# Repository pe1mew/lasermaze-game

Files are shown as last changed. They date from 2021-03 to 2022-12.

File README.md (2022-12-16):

# lasermaze-game
A laser maze game designed for BULA2022 

# Work in progress
This is work in progress. Thing may be added or changed without notice.

# Directions
The Architecture of the laser maze can be found [here](Architecture/architecture.md).

# Questions?
If you have any question? please raise an issue and I will ook in to it.

### Disclaimer
The lasermaze-game is distributed in the hope that it will be useful, but WITHOUT ANY WARRANTY; without even the 
implied warranty of MERCHANTABILITY or FITNESS FOR A PARTICULAR PURPOSE.
  
### License
The lasermaze-game is free software and hardware: 
you can redistribute it and/or modify it under the terms of a Creative Commons Attribution-NonCommercial 4.0 International License (http://creativecommons.org/licenses/by-nc/4.0/) by PE1MEW (http://pe1mew.nl) E-mail: pe1mew@pe1mew.nl

<br />This work is licensed under a <a rel="license" href="http://creativecommons.org/licenses/by-nc/4.0/">Creative Commons Attribution-NonCommercial 4.0 International License</a>.

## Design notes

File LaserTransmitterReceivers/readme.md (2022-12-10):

# What to use, where to buy

The following links provide an example. Find the cheapest yourself!

## Transmitter
The laser transmitters are [KY-008 650nm Laser sensor Module 6mm 5V 5mW Red Laser Dot Diode Copper Head KY008](https://www.aliexpress.com/item/4000693969769.html?spm=a2g0o.cart.0.0.43a738dam0hMLE&mp=1) as can found Aliexpress or a equivalent.

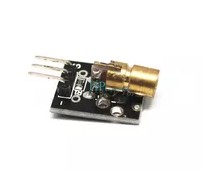
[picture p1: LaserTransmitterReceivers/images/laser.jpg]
laser


## Receptor
For the receivers a LDR prototype board is used: [Photoresistor (LDR) Sensor Module Detects Light Sensitive Photodiode for Arduino](https://www.aliexpress.com/item/32452315745.html) as can found Aliexpress or a equivalent.

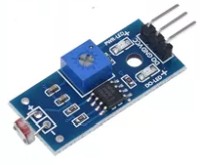
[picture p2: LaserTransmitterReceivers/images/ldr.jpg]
ldr


## Magnets
The magnets to stick the receptors and transmittors to a metal object are [Circular Magnets sheet 15mm X 6mm Round Neodymium Magnet Strong N35 15x6mm Permanent Disc Magnet 15*6 mm](https://www.aliexpress.com/item/1005001581640011.html) as can be found on Aliexpress.

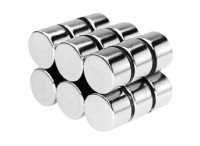
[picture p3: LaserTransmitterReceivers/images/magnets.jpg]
magnets


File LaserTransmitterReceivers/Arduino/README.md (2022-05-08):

# Software for ESP8266 GPIO TX and RX controller
This is the software for the ESP8266 controller boards

## Depenencies
The following dependencies shall be adressed:

### Arduino IDE
Although the software can be used in platformio without any problem, this repository is providing setup for Arduino IDE. 

 - Download the latetst version of Arduino from https://support.arduino.cc/hc/en-us/categories/360002212660-Software-and-Downloads

### Install ESP8266 Board support
 - In settings, add the following url for board support: ```http://arduino.esp8266.com/stable/package_esp8266com_index.json```
 - In "Tools > Board: -> Boards Manager..."  add ESP8266 comunity boards.
 
### Install libraries
 - In "Sketch > Include Library -> Manage Libraries..."  add "PubSubClient" by Nick O'Leary.

## Transmitter

## Receptor

### Disclaimer
The lasermaze-game is distributed in the hope that it will be useful, but WITHOUT ANY WARRANTY; without even the 
implied warranty of MERCHANTABILITY or FITNESS FOR A PARTICULAR PURPOSE.
  
### License
The lasermaze-game is free software and hardware: 
you can redistribute it and/or modify it under the terms of a Creative Commons Attribution-NonCommercial 4.0 International License (http://creativecommons.org/licenses/by-nc/4.0/) by PE1MEW (http://pe1mew.nl) E-mail: pe1mew@pe1mew.nl

<br />This work is licensed under a <a rel="license" href="http://creativecommons.org/licenses/by-nc/4.0/">Creative Commons Attribution-NonCommercial 4.0 International License</a>.

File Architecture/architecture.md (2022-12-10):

# Architecture

The lasermaze is build upon a Raspberry-Pi with Node-red and is visualised in the following component diagram: 

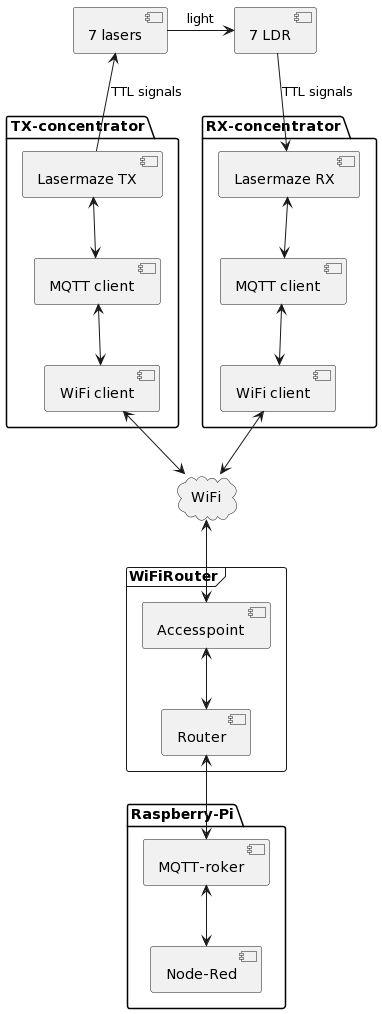
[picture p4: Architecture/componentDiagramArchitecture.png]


The lasers and receivers are connected to a concentrator who control the transmitters and read the receivers. The concentrators connect to the WiFi network so that the MQTT client in the concentrator can connect to the MQTT broker for command and control. 

The Node-red instance is running flows that will implement the game logic. Nod-red is connected to the MQTT broker for command and control of the concentrators.

Lasers are swithed on and off with a messgage in the associated MQTT topic. Receivers report their status on change (detect light or not) with a messgage in the associated MQTT topic. 

At a regular interval the concentrators are polled by the game logic in Node-red. This will allow detection of missed messages as well as a an indication that a concentrator is connected. A connected concentrator that is polled regularly will have a red- blinking led.

## Software
The software required for the Lasermaze is: 

 - Node-red (hart of the system)
 - mosquitto MQTT broker (to interconnect all components of the lasermaze)
 - Arduino (to program the ESP8266)
 - Programcode for the TX- and RX-concentrators. (Avialable in this repository)

## Hardware
The following hardware is required:

 - A computer that can run the software specified above (I used a Raspberry-Pi 4 with a touch screen)
 - Any Wifi-accesspoint with a router that has a DHCP-server. 
 - ESP8266 D1 mini for each TX- and RX-concentrator (fits on the concentrator boards in this repository) 
 - Laser emitters (see [components specified here..](../LaserTransmitterReceivers/readme.md))
 - LDR light detectors (see [components specified here..](../LaserTransmitterReceivers/readme.md))
 - Magnets are optional (see [components specified here..](../LaserTransmitterReceivers/readme.md)
 - PLA to print the laser transmitter and receiver mounts.

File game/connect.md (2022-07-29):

# Connection details of laser emitters and detectors

## emitter

```
            Wire connector
   +---------+-----+
   |         |  0  | negative (-) ground
+-------+    +-----+
| laser |    |  0  | 
+-------+    +-----+
   |         |  0  | positive (+) VCC
   +---------+-----+

```

## detector

```
            Wire connector
   +---+---+-+-----+
   |   | P | |  0  | positive (+) VCC
  /-\  +---+ +-----+
 |LDR|       |  0  | negative (-) ground
  \-/        +-----+
   |         |  0  | output 
   +---------+-----+

```

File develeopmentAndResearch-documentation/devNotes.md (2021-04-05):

# Development notes
These notes contain all information about the architecture and implementation details of the lasermaze. 

# information

## painlessMesh
This a mesh at layer 3 of the OSI-model that implements a network layer. It is connectionless and without confirmation. (See: https://gitlab.com/painlessMesh/painlessMesh/-/wikis/home) Messages are not acknowledged. This should be implemented at application level. 

# LaserMaze requirements

- Detection of events shall not be missed.
- Events shall be transported "fast" to the cental processing unit. (what "fast enough" is shall be determinated)

# Lasermaze architecture.

laser maze is build of the following units:

1. Laser transmitter-detector pairs.
2. transmitter and detector controllers.
3. Auxillary devices like sirens, stobe lights, buttons, PIR-detectors.
3. Auxillary controllers for input and output devices. 
4. controller to MQTT bridge.
5. central game contoller. 

## Laser transmitter-detector pairs. 
These pairs consist of a laser transmitter and a laser detector. Both are installed oposite of each other and controlled by a concentrator that serves a group of lasers and detectors.

## transmitter and detector controllers.
A controller serves only inputs or outputs transmitters or detectors. The maximum number of transmitters or detectors is 8 per concentrator

## Auxillary devices
Auxillary devices are devices that add elements to the game other than the laser transmitters or detectors. 
These can be: 

- outputs: 
	- sirens, 
	- stobe lights, 
- Inputs: 
	- buttons, 
	- PIR-detectors,
- etc.

## Auxillary controllers

## controller to MQTT bridge

## central game contoller.

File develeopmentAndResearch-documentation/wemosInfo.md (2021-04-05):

# wemose ESP8266 D1 Mini

# pin-layout

D1 Mini|GPIO|Type|Function                       |Lasermaze
-------|----|----|-------------------------------|--------------
TX     |1   |I/O |TXD Transmit Data              |Not available
RX     |3   |I/O |RXD Receive Data               |Not available
A0     |A0  |I   |Analog-Input (max. 3,3V)       |tbd.
D0     |16  |I/O |                               |Available
D1     |5   |I/O |SCL I2C Interface              |Available
D2     |4   |I/O |SDA I2C Interface              |Available
D3     |0   |I/O |10k Pull-Up                    |Available
D4     |2   |I/O |10k Pull-Up Built-in LED       |tbd.
D5     |14  |I/O |SCK SPI Interface              |Available
D6     |12  |I/O |MISO SPI Interface             |Available
D7     |13  |I/O |MOSI SPI Interface             |Available
D8     |15  |I/O |SS 10k Pull-Down SPI Interface |Available
G      |GND |-   |Ground                         |
5V     |5V  |I   |RAW VCC (5V)                   |
3V3    |3V3 |O   |3,3V output                    |
RST    |RST |I   |Reset                          |

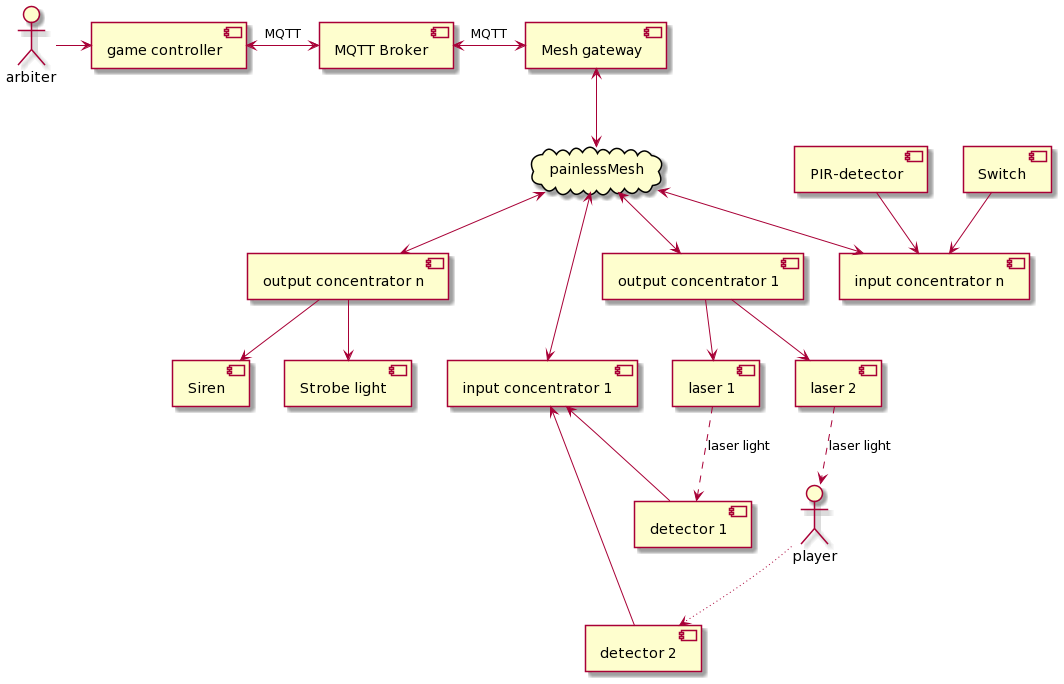
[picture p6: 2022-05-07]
develeopmentAndResearch-documentation/images/PlantUMLComponentDiagram.png

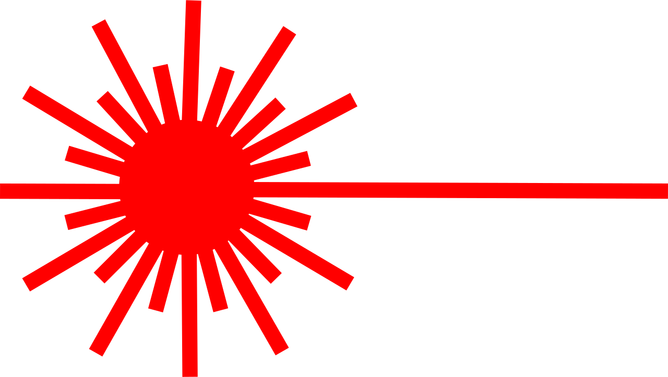
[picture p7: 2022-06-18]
develeopmentAndResearch-documentation/inspiration/1280px-Sailing_laser.svg.png

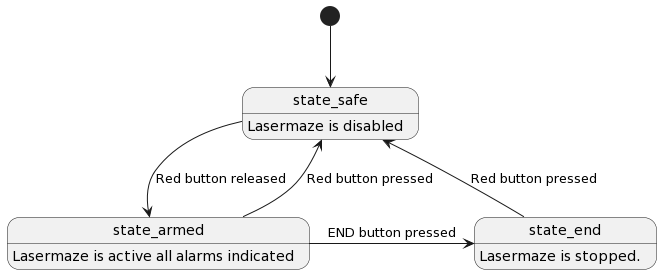
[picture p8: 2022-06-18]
NodeRed/stateDiagram.png

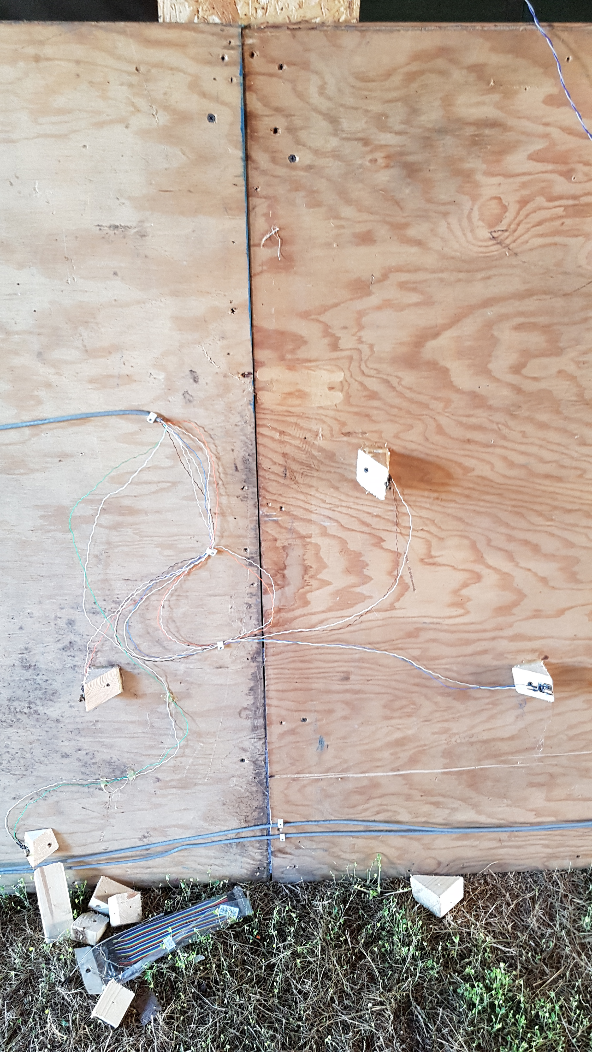
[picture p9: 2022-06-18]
develeopmentAndResearch-documentation/inspiration/2018-08-10 10.22.27.jpg

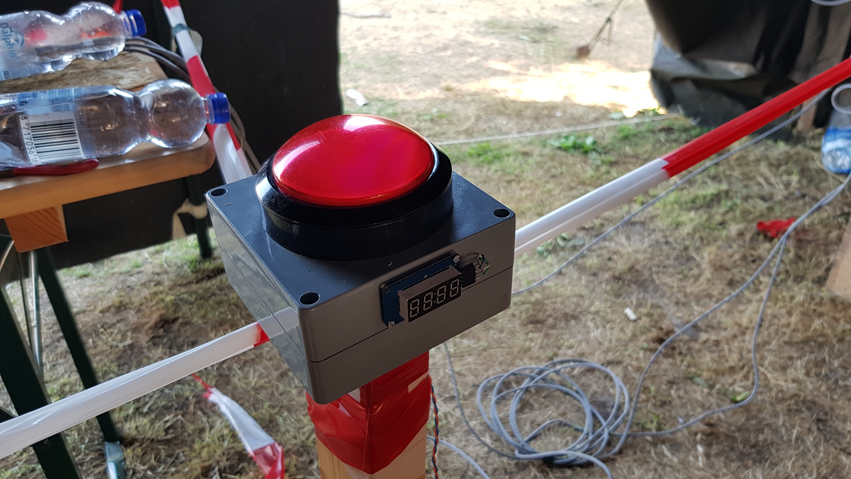
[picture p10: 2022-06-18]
develeopmentAndResearch-documentation/inspiration/2018-08-10 10.23.28.jpg

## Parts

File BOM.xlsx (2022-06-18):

 | Reference | Quantity | totaal | Value | Footprint | aanwezig
Relay | C1 | 1 | 2 | 0,22uF | Capacitor_THT:CP_Radial_D5.0mm_P2.00mm
Relay | C3 C4 C5 C6 C15 C16 C17 C18 | 8 | 8 | 1n | Capacitor_SMD:C_0805_2012Metric_Pad1.18x1.45mm_HandSolder
Relay | C2 | 1 | 2 | 0,1uF | Capacitor_THT:CP_Radial_D5.0mm_P2.00mm
Relay | D1 | 1 | 1 | 1N4007 | Diode_THT:D_DO-41_SOD81_P12.70mm_Horizontal
Relay | D3 D4 D5 D6 D10 D11 D12 D13 | 8 | 8 | LED | LED_SMD:LED_0805_2012Metric_Pad1.15x1.40mm_HandSolder
Relay | D7 D8 D9 D14 D15 D16 D17 D18 | 8 | 16 | 1N4148 | Diode_THT:D_DO-35_SOD27_P7.62mm_Horizontal
Relay | D2 | 1 | 2 | GREEN | LED_SMD:LED_0805_2012Metric_Pad1.15x1.40mm_HandSolder
Relay | J1 - J9 | 9 | 9 | V-IN | TerminalBlock:TerminalBlock_Altech_AK300-2_P5.00mm
Relay | Q1 Q2 Q3 Q4 Q5 Q6 Q7 Q8 | 8 | 8 | 85N3LHS | Package_TO_SOT_THT:SIPAK_Vertical
Relay | R2 R3 R4 R5 R10 R11 R12 R13 | 8 | 8 | 1k | Resistor_SMD:R_0805_2012Metric_Pad1.20x1.40mm_HandSolder
Relay | R1 R6 R7 R8 R9 R14 R15 R16 R17 | 9 | 9 | 150ohm | Resistor_SMD:R_0805_2012Metric_Pad1.20x1.40mm_HandSolder
Relay | R18 R19 R20 R21 R22 R23 R24 R25 | 8 | 8 | SRD-05VDC-SL-C | components:SRD-05VDC-SL-C | TRUE
Relay | U1 | 1 | 2 | WeMos_D1_mini | Module:WEMOS_D1_mini_light | TRUE
Relay | U2 | 1 | 2 | L7805 | Package_TO_SOT_THT:TO-220-3_Horizontal_TabDown
InOut | C1 | 1 | 6 | 0,22uF | Capacitor_THT:CP_Radial_D5.0mm_P2.00mm
InOut | C2 | 1 | 6 | 0,1uF | Capacitor_THT:CP_Radial_D5.0mm_P2.00mm
InOut | C3 C4 C5 C6 C7 C8 C9 C10 C11 C12 C13 C14 C15 C16 C17 C18 C19 C20 C21 C22 C23 C24 C25 C26 | 24 | 72 | 1n | Capacitor_SMD:C_0805_2012Metric_Pad1.18x1.45mm_HandSolder
InOut | D1 | 1 | 6 | 1N4007 | Diode_THT:D_DO-41_SOD81_P12.70mm_Horizontal
Output | D3 D4 D5 D6 D10 D11 D12 D13 | 8 | 24 | LED | LED_SMD:LED_0805_2012Metric_Pad1.15x1.40mm_HandSolder
Output | D7 D8 D9 D14 D15 D16 D17 | 7 | 21 | BAT54S | Package_TO_SOT_SMD:SOT-23
InOut | D2 | 1 | 6 | GREEN | LED_SMD:LED_0805_2012Metric_Pad1.15x1.40mm_HandSolder
Always | J1-J9 | 9 | 54 | V-IN | TerminalBlock:TerminalBlock_Altech_AK300-2_P5.00mm
InOut | JP1 JP2 JP3 JP4 JP5 JP6 JP7 | 7 | 42 | inputEnable | Jumpers:SMT-JUMPER_2_NO_SILK
Output | Q1 Q2 Q3 Q4 Q5 Q6 Q7 Q8 | 8 | 24 | 85N3LHS | Package_TO_SOT_THT:SIPAK_Vertical
Output | R2 R3 R4 R5 R10 R11 R12 R13 | 8 | 24 | 1k | Resistor_SMD:R_0805_2012Metric_Pad1.20x1.40mm_HandSolder
Output | R1 R6 R7 R8 R9 R14 R15 R16 R17 | 9 | 27 | 150ohm | Resistor_SMD:R_0805_2012Metric_Pad1.20x1.40mm_HandSolder
InOut | U1 | 1 | 6 | WeMos_D1_mini | Module:WEMOS_D1_mini_light | TRUE
InOut | U2 | 1 | 6 | L7805 | Package_TO_SOT_THT:TO-220-3_Horizontal_TabDown
 | PCB sets of 2 |  | 3
 |  | 8 |  | 0,1uF | Capacitor_THT:CP_Radial_D5.0mm_P2.00mm
 |  | 8 |  | 0,22uF | Capacitor_THT:CP_Radial_D5.0mm_P2.00mm
 |  | 36 |  | 150ohm | Resistor_SMD:R_0805_2012Metric_Pad1.20x1.40mm_HandSolder
 |  | 32 |  | 1k | Resistor_SMD:R_0805_2012Metric_Pad1.20x1.40mm_HandSolder
 |  | 80 |  | 1n | Capacitor_SMD:C_0805_2012Metric_Pad1.18x1.45mm_HandSolder
 |  | 7 |  | 1N4007 | Diode_THT:D_DO-41_SOD81_P12.70mm_Horizontal
 |  | 16 |  | 1N4148 | Diode_THT:D_DO-35_SOD27_P7.62mm_Horizontal
 |  | 32 |  | 85N3LHS | Package_TO_SOT_THT:SIPAK_Vertical
 |  | 21 |  | BAT54S | Package_TO_SOT_SMD:SOT-23
 |  | 8 |  | GREEN | LED_SMD:LED_0805_2012Metric_Pad1.15x1.40mm_HandSolder
 |  | 8 |  | L7805 | Package_TO_SOT_THT:TO-220-3_Horizontal_TabDown
 |  | 32 |  | LED | LED_SMD:LED_0805_2012Metric_Pad1.15x1.40mm_HandSolder
 |  | 8 |  | SRD-05VDC-SL-C | components:SRD-05VDC-SL-C
 |  | 63 |  | V-IN | TerminalBlock:TerminalBlock_Altech_AK300-2_P5.00mm
 |  | 8 |  | WeMos_D1_mini | Module:WEMOS_D1_mini_light

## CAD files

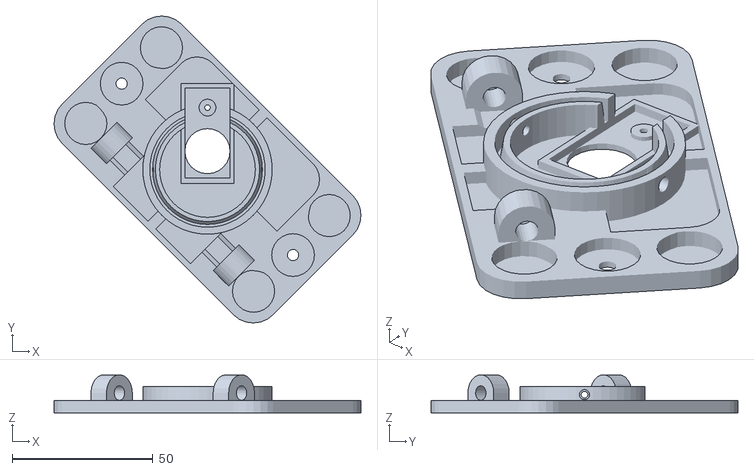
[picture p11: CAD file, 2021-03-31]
LaserTransmitterReceivers/3d/laserReceptor/LaserMazeReceptor_020_fixed.stl
109.1 x 109.1 x 13.5

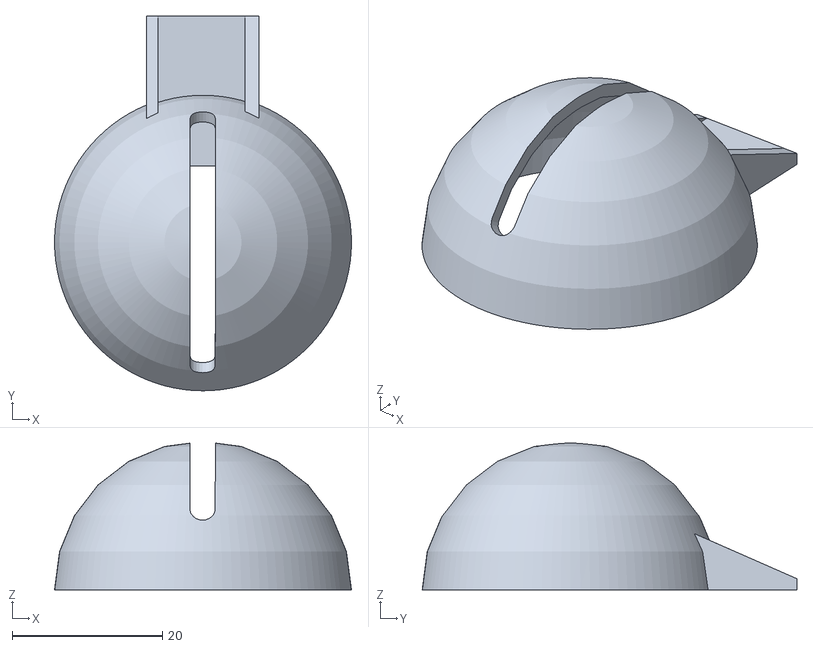
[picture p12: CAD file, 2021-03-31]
LaserTransmitterReceivers/3d/laserTransmitter/LaserMazeTransmitterInsert_007_fixed.stl
39.6 x 50.0 x 19.6

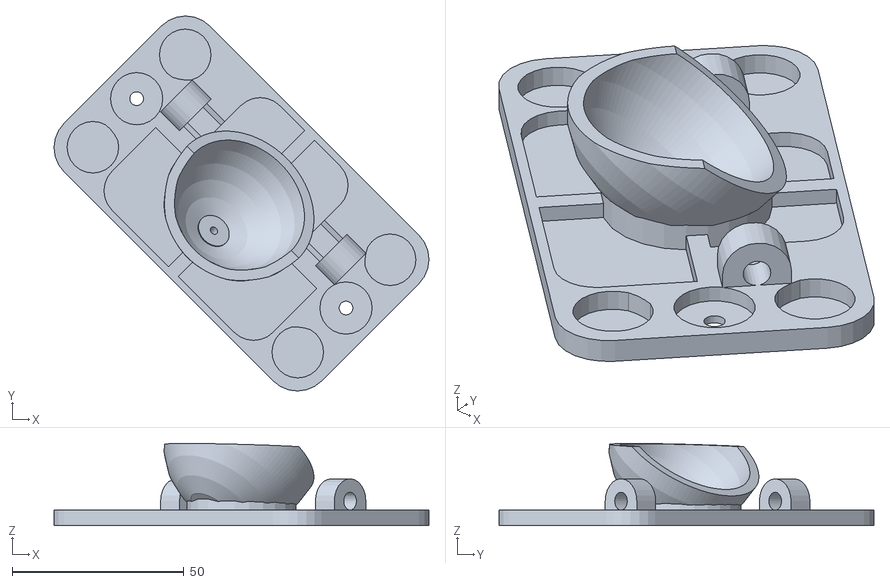
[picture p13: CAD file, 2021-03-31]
LaserTransmitterReceivers/3d/laserTransmitter/LaserMazeTransmitter_012_fixed.stl
109.1 x 109.1 x 23.9

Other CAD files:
LaserTransmitterReceivers/3d/laserReceptor/LaserMazeReceptor_020.skp
LaserTransmitterReceivers/3d/laserTransmitter/LaserMazeTransmitterInsert_007.skp
LaserTransmitterReceivers/3d/laserTransmitter/LaserMazeTransmitter_012.skp

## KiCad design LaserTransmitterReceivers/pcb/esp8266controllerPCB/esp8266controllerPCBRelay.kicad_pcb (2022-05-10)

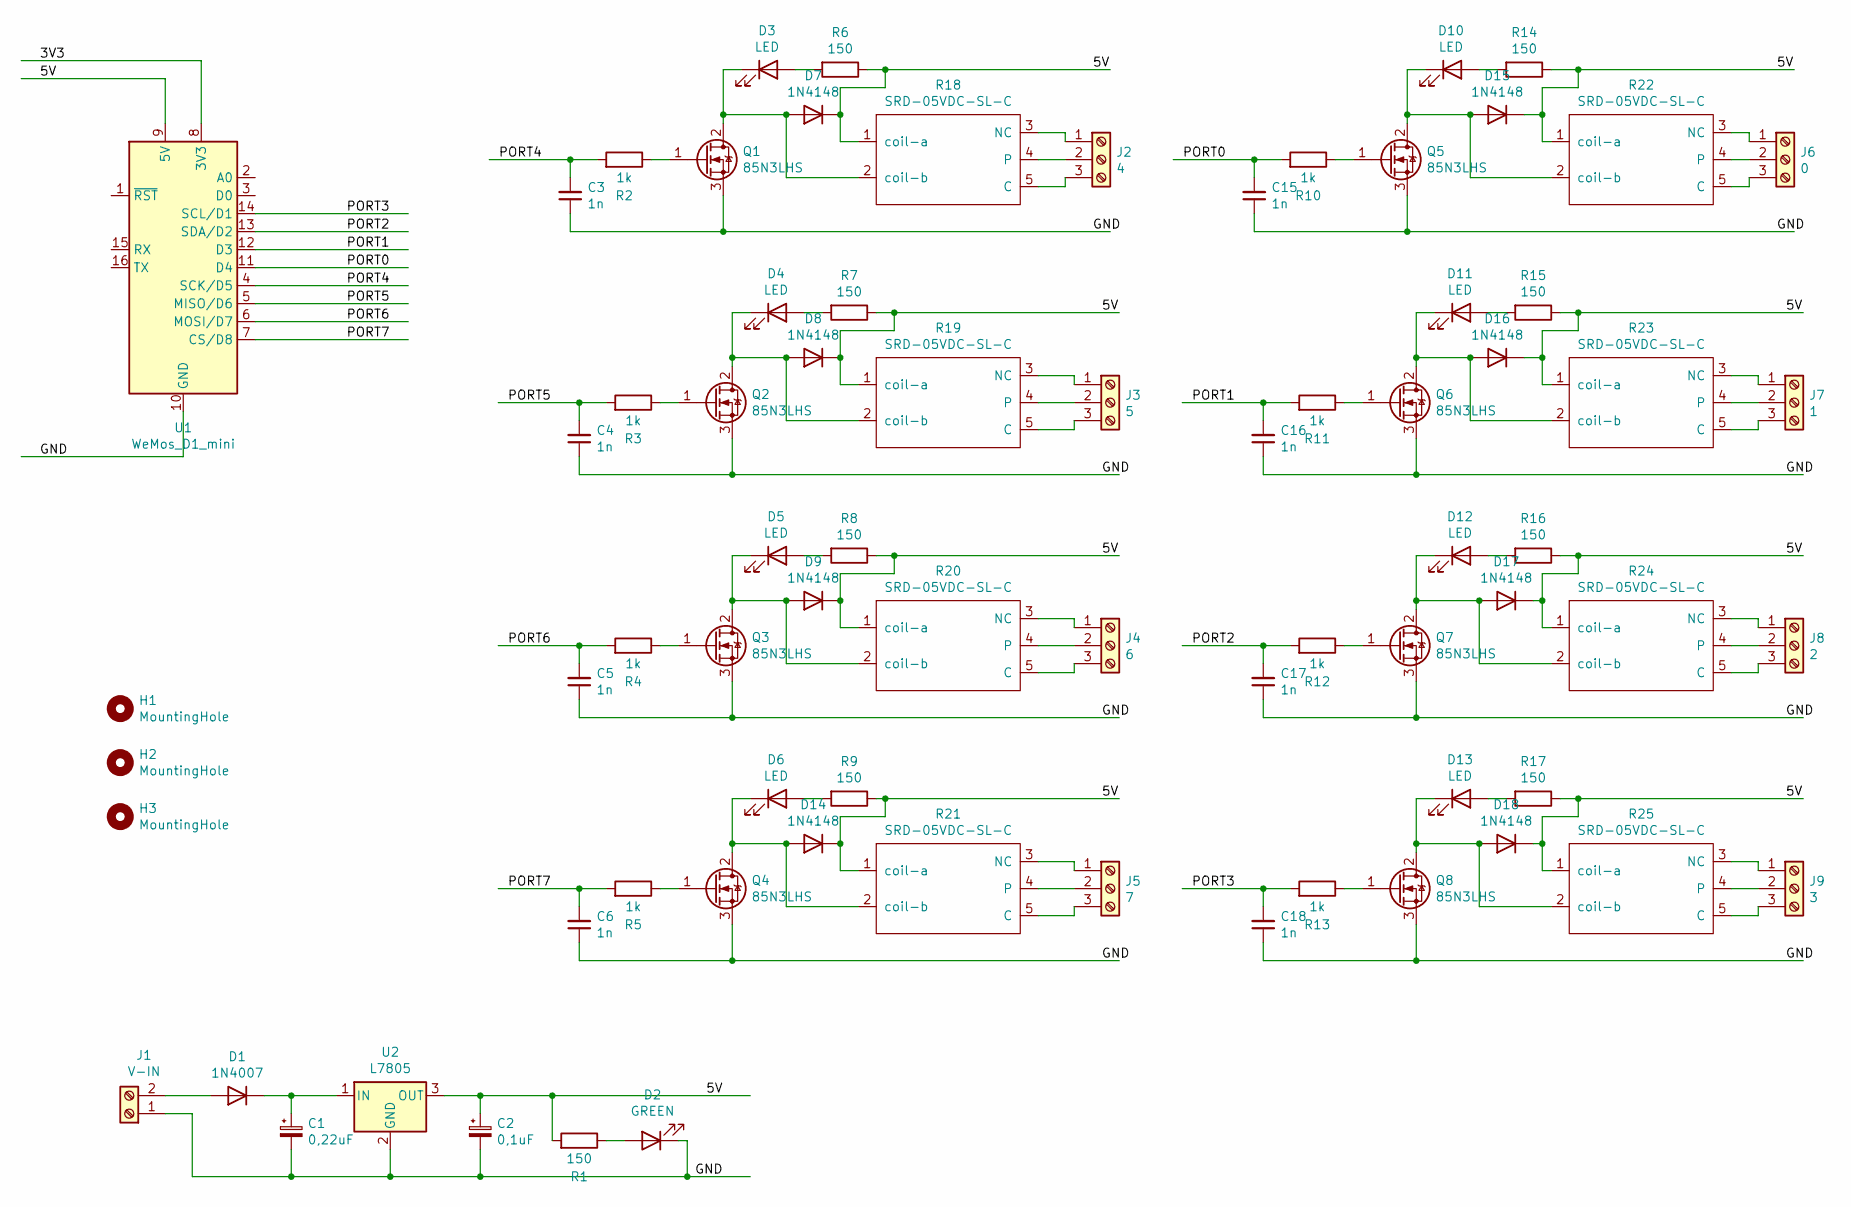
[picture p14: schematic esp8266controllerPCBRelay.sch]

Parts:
C1: 0,22uF; CP_Radial_D5.0mm_P2.00mm
C2: 0,1uF; CP_Radial_D5.0mm_P2.00mm
C3, C4, C5, C6, C15, C16, C17, C18: 1n; C_0805_2012Metric_Pad1.18x1.45mm_HandSolder
D1: 1N4007; D_DO-41_SOD81_P12.70mm_Horizontal
D2: GREEN; LED_0805_2012Metric_Pad1.15x1.40mm_HandSolder
D3, D4, D5, D6, D10, D11, D12, D13: LED; LED_0805_2012Metric_Pad1.15x1.40mm_HandSolder
D7, D8, D9, D14, D15, D16, D17, D18: 1N4148; D_DO-35_SOD27_P7.62mm_Horizontal
H1, H2, H3: MountingHole; MountingHole_6mm
J1: V-IN; TerminalBlock_Altech_AK300-2_P5.00mm
J2: 4; TerminalBlock_Altech_AK300-3_P5.00mm
J3: 5; TerminalBlock_Altech_AK300-3_P5.00mm
J4: 6; TerminalBlock_Altech_AK300-3_P5.00mm
J5: 7; TerminalBlock_Altech_AK300-3_P5.00mm
J6: 0; TerminalBlock_Altech_AK300-3_P5.00mm
J7: 1; TerminalBlock_Altech_AK300-3_P5.00mm
J8: 2; TerminalBlock_Altech_AK300-3_P5.00mm
J9: 3; TerminalBlock_Altech_AK300-3_P5.00mm
Q1, Q2, Q3, Q4, Q5, Q6, Q7, Q8: 85N3LHS; SIPAK_Vertical
R1, R6, R7, R8, R9, R14, R15, R16, R17: 150; R_0805_2012Metric_Pad1.20x1.40mm_HandSolder
R2, R3, R4, R5, R10, R11, R12, R13: 1k; R_0805_2012Metric_Pad1.20x1.40mm_HandSolder
R18, R19, R20, R21, R22, R23, R24, R25: SRD-05VDC-SL-C
U1: WeMos_D1_mini; WEMOS_D1_mini_light
U2: L7805; TO-220-3_Horizontal_TabDown

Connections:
/5V: C2.1, D7.1 (K), D8.1 (K), D9.1 (K), D14.1 (K), D15.1 (K), D16.1 (K), D17.1 (K), D18.1 (K), R1.2, R6.1, R7.1, R8.1, R9.1, R14.1, R15.1, R16.1, R17.1, R18.1 (coil-a), R19.1 (coil-a), R20.1 (coil-a), R21.1 (coil-a), R22.1 (coil-a), R23.1 (coil-a), R24.1 (coil-a), R25.1 (coil-a), U1.9 (5V), U2.3 (OUT)
/GND: C1.2, C2.2, C3.1, C4.1, C5.1, C6.1, C15.1, C16.1, C17.1, C18.1, D2.1 (K), J1.1, Q1.3 (S), Q2.3 (S), Q3.3 (S), Q4.3 (S), Q5.3 (S), Q6.3 (S), Q7.3 (S), Q8.3 (S), U1.10 (GND), U2.2 (GND)
/PORT0: C15.2, R10.2, U1.11 (D4)
/PORT1: C16.2, R11.2, U1.12 (D3)
/PORT2: C17.2, R12.2, U1.13 (SDA/D2)
/PORT3: C18.2, R13.2, U1.14 (SCL/D1)
/PORT4: C3.2, R2.2, U1.4 (SCK/D5)
/PORT5: C4.2, R3.2, U1.5 (MISO/D6)
/PORT6: C5.2, R4.2, U1.6 (MOSI/D7)
/PORT7: C6.2, R5.2, U1.7 (CS/D8)
unnamed: C1.1, D1.1 (K), U2.1 (IN)
unnamed: D1.2 (A), J1.2
unnamed: D2.2 (A), R1.1
unnamed: D3.1 (K), D7.2 (A), Q1.2 (D), R18.2 (coil-b)
unnamed: D3.2 (A), R6.2
unnamed: D4.1 (K), D8.2 (A), Q2.2 (D), R19.2 (coil-b)
unnamed: D4.2 (A), R7.2
unnamed: D5.1 (K), D9.2 (A), Q3.2 (D), R20.2 (coil-b)
unnamed: D5.2 (A), R8.2
unnamed: D6.2 (A), R9.2
unnamed: D10.1 (K), D15.2 (A), Q5.2 (D), R22.2 (coil-b)
unnamed: D10.2 (A), R14.2
unnamed: D11.1 (K), D16.2 (A), Q6.2 (D), R23.2 (coil-b)
unnamed: D11.2 (A), R15.2
unnamed: D12.1 (K), D17.2 (A), Q7.2 (D), R24.2 (coil-b)
unnamed: D12.2 (A), R16.2
unnamed: D13.1 (K), D18.2 (A), Q8.2 (D), R25.2 (coil-b)
unnamed: D13.2 (A), R17.2
unnamed: D6.1 (K), D14.2 (A), Q4.2 (D), R21.2 (coil-b)
unnamed: J2.1, R18.3 (NC)
unnamed: J2.2, R18.4
unnamed: J2.3, R18.5 (C)
unnamed: J3.1, R19.3 (NC)
unnamed: J3.2, R19.4
unnamed: J3.3, R19.5 (C)
unnamed: J4.1, R20.3 (NC)
unnamed: J4.2, R20.4
unnamed: J4.3, R20.5 (C)
unnamed: J5.1, R21.3 (NC)
unnamed: J5.2, R21.4
unnamed: J5.3, R21.5 (C)
unnamed: J6.1, R22.3 (NC)
unnamed: J6.2, R22.4
unnamed: J6.3, R22.5 (C)
unnamed: J7.1, R23.3 (NC)
unnamed: J7.2, R23.4
unnamed: J7.3, R23.5 (C)
unnamed: J8.1, R24.3 (NC)
unnamed: J8.2, R24.4
unnamed: J8.3, R24.5 (C)
unnamed: J9.1, R25.3 (NC)
unnamed: J9.2, R25.4
unnamed: J9.3, R25.5 (C)
unnamed: Q1.1 (G), R2.1
unnamed: Q2.1 (G), R3.1
unnamed: Q3.1 (G), R4.1
unnamed: Q4.1 (G), R5.1
unnamed: Q5.1 (G), R10.1
unnamed: Q6.1 (G), R11.1
unnamed: Q7.1 (G), R12.1
unnamed: Q8.1 (G), R13.1

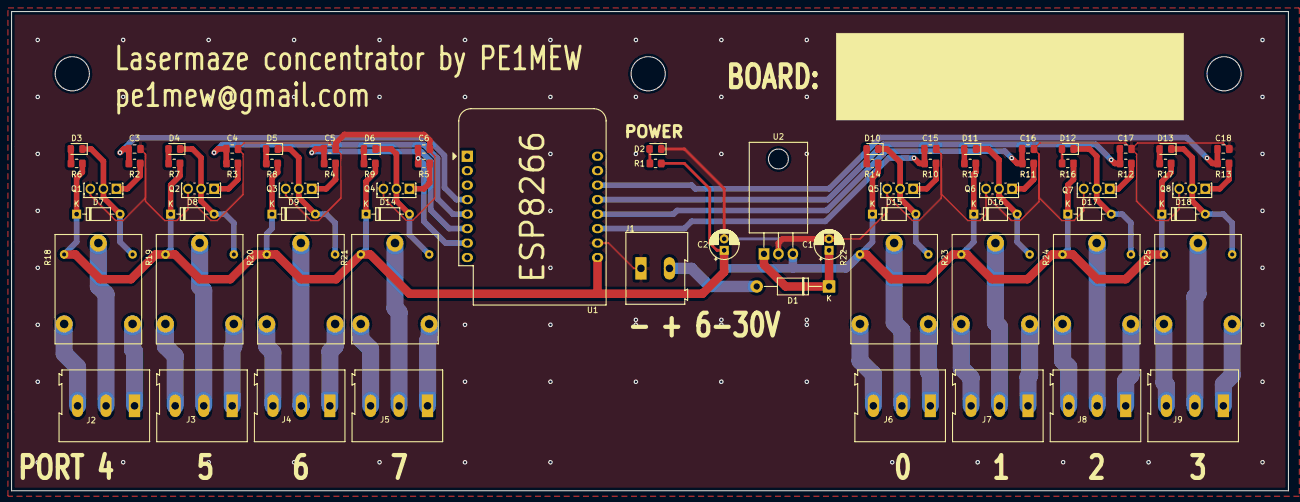
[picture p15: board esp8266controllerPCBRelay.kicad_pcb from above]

Board: 2 copper layers, 224.2 x 84.1 mm, 75 parts (0 on the bottom side), 61 nets.

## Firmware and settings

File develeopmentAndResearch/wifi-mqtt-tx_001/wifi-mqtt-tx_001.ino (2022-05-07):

/*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
  The program is distributed in the hope that it will be useful,
  but WITHOUT ANY WARRANTY; without even the implied warranty of
  MERCHANTABILITY or FITNESS FOR A PARTICULAR PURPOSE.
  --------------------------------------------------------------------*/

/*!
 * \file wifi-mqtt-tx_001.ino
 * \brief Posts changes on GPIO ports on MQTT through a WiFi connection .
 * Inspired on: https://techtutorialsx.com/2017/04/09/esp8266-connecting-to-mqtt-broker/
 * \author Remko Welling (pe1mew@gmail.com)
 * 
 * # Revision history
 * 
 * Version|Date      |Note
 * --------------------------------------
 * 0.1    |7-5-2022  | Initial release
 * 
 * 
 * 
 */
 
#include <ESP8266WiFi.h>
#include <PubSubClient.h>

#include <string.h> // memset()

const int OUTPUT_0_PIN = 2;   // GPIO2  D4
const int OUTPUT_1_PIN = 0;   // GPIO0  D3
const int OUTPUT_2_PIN = 4;   // GPIO4  D2
const int OUTPUT_3_PIN = 5;   // GPIO5  D1
const int OUTPUT_4_PIN = 14;  // GPIO14 D5/SCK
const int OUTPUT_5_PIN = 12;  // GPIO12 D6/MISO
const int OUTPUT_6_PIN = 13;  // GPIO13 D7/MOSI
const int OUTPUT_7_PIN = 15;

uint8_t outputState    = 0x00;
uint8_t newOutputState = 0xFF;
bool    setState       = false;
bool    sendState      = false;
 
const char*   WiFissid           = "laserbase"; ///< SSID of WiFi access point
const char*   WiFipassword       = "laserbase"; ///< passwordt for WiFi accesspoint
unsigned long WiFipreviousMillis = 0;           ///< Variable to hold last moment on which WiFi connection is tested. 
unsigned long WiFiinterval       = 30000;       ///< inteval in milliseconds at which WiFi connection is tested.

const char* mqttServer   = "172.31.0.10";       ///< MQTT broker address or IP
const int   mqttPort     = 1883;                ///< MQTT broker portnumber
const char* mqttUser     = "remko";             ///< MQTT username for access to broker
const char* mqttPassword = "remko";             ///< MQTT password for access to broker

const String baseTopic   = "lasermaze/";        ///< Base topic for topic structure on broker
String subscribeTopic;
uint32_t chipId;                                ///< Chip ID as retrieved from ESP8266 in setup()
String topic;                                   ///< Topic to be used prefixing other publications and subscriptions
#define TOPIC_BUFFER_SIZE 50                    ///< Size of helper buffer
char topicBuffer[TOPIC_BUFFER_SIZE];            ///< helper buffer for conversions of topics in String format.
       
WiFiClient espClient;                           ///< WiFi opbject on ESP8266
PubSubClient client(espClient);                 ///< MQTT client object
 
/// \brief initialize WiFi on ESP8266
void WiFiinit() {
  WiFi.mode(WIFI_STA);
  WiFi.begin(WiFissid, WiFipassword);
  Serial.print("WIFI: Connecting...\n");
  while (WiFi.status() != WL_CONNECTED) {
    Serial.print('.');
    delay(1000);
  }
  Serial.print("\nWiFi: ");
  Serial.println(WiFi.localIP());
  //The ESP8266 tries to reconnect automatically when the connection is lost
  WiFi.setAutoReconnect(true);
  WiFi.persistent(true);
}

/// \brief test if WiFi is connected and reconnect when disconnected. 
/// When connected the RSSI is printed and published on MQTT
/// This function acivates every WiFiinterval in milliseconds
void WiFireconnect(){
  unsigned long WiFicurrentMillis = millis();
  if (WiFicurrentMillis - WiFipreviousMillis >= WiFiinterval){
    switch (WiFi.status()){
      case WL_NO_SSID_AVAIL:
        Serial.println("WiFi: SSID cannot be reached");
        break;
      case WL_CONNECTED:
        Serial.printf("WiFi: Connected, status: %d, RSSI: %d dBm.\n", WiFi.status(), WiFi.RSSI());
        break;
      case WL_CONNECT_FAILED:
        Serial.println("WiFi: Connection failed");
        break;
    }

    if(client.connected()){
      memset(topicBuffer, 0, TOPIC_BUFFER_SIZE);
      String tempTopic = topic + "wifi/rssi/";
      tempTopic.toCharArray(topicBuffer, TOPIC_BUFFER_SIZE);
      char payload[10] = "\0";
      itoa(WiFi.RSSI(), payload, 10);
      client.publish(topicBuffer, payload);
    }
    WiFipreviousMillis = WiFicurrentMillis;
  }
}

/// \brief Initialize MQTT client and connect to broker.
void MQTTinit() {
  client.setServer(mqttServer, mqttPort);
  client.setCallback(MQTTcallback);
  MQTTreconnect();
}

/// \brief test is MQTT client is connected and reconnect when not connected. 
void MQTTreconnect(){
  while (!client.connected()) {
    Serial.println("MQTT: Connecting...");
    char clientID[10] = "\0";
    itoa(chipId, clientID, 10);
    if (client.connect(clientID, mqttUser, mqttPassword )) {
      Serial.println("MQTT: Connected");
      memset(topicBuffer, 0, TOPIC_BUFFER_SIZE);
      topic.toCharArray(topicBuffer, 50);
      client.publish(topicBuffer, "Hello world");
      memset(topicBuffer, 0, TOPIC_BUFFER_SIZE);
      subscribeTopic.toCharArray(topicBuffer, 50);
      client.subscribe(topicBuffer);
      setState = true;     // send actual input state after MQTT reconnect
      sendState = true;     // send actual input state after MQTT reconnect
    } else {
      Serial.print("MQTT: Failed with state ");
      Serial.println(client.state());
      delay(2000);
    }
  }
}

/// \brief Setup ESP8266
void setup() {
  Serial.begin(115200);

  pinMode(OUTPUT_0_PIN, OUTPUT);
  pinMode(OUTPUT_1_PIN, OUTPUT);
  pinMode(OUTPUT_2_PIN, OUTPUT);
  pinMode(OUTPUT_3_PIN, OUTPUT);
  pinMode(OUTPUT_4_PIN, OUTPUT);
  pinMode(OUTPUT_5_PIN, OUTPUT);
  pinMode(OUTPUT_6_PIN, OUTPUT);
  pinMode(OUTPUT_7_PIN, OUTPUT);

  chipId = ESP.getChipId();
  Serial.print("\nChipID: ");
  Serial.println(chipId);
  topic = baseTopic + chipId + "/";
  Serial.println(topic);
  subscribeTopic = topic + "output/#";
  Serial.println(subscribeTopic);
  
  WiFiinit();
  MQTTinit();
}

/// \brief callback function when MQTT message is received. 
void MQTTcallback(char* topic, byte* payload, unsigned int length) {
  Serial.print("MQTT: Message in topic: ");
  Serial.print(topic);
  Serial.print(", Payload: ");
  for (int i = 0; i < length; i++) {
    Serial.print((char)payload[i]);
  }
  Serial.print("\n");

  memset(topicBuffer, 0, TOPIC_BUFFER_SIZE);
  strncpy(topicBuffer, topic + 19, 6);
  
  if (strcmp(topicBuffer, "output") == 0){
    char gpio[5] = "\0";
    strncpy(gpio, topic + 26, 1);
    uint8_t port = atoi(gpio);
    char payloadBuffer[5] = "\0";
    strncpy(payloadBuffer, (char*)payload, 1);
    uint8_t state = (atoi(payloadBuffer) & 0x01);
    
    if(port < 8){ // valid port selected
      if(state == 0){  // Set port
        newOutputState &= ~(1 << port);
      }else{
        newOutputState |= (1 << port);
      }
    }else{
      sendState = true;
    }
  } 
}

/// \brief Main loop.
void loop() {
  client.loop();
        
  WiFireconnect();
  MQTTreconnect();

  if((newOutputState != outputState) || setState){
    printGPIO(newOutputState);
    
    // Test ouput pin 0
    if((newOutputState & 0x01) == 0){
      digitalWrite(OUTPUT_0_PIN, LOW);  
    }else{
      digitalWrite(OUTPUT_0_PIN, HIGH);
    }
    
    // Test ouput pin 1
    if((newOutputState & 0x02) == 0){
      digitalWrite(OUTPUT_1_PIN, LOW);  
    }else{
      digitalWrite(OUTPUT_1_PIN, HIGH);
    }
    
    // Test ouput pin 2
    if((newOutputState & 0x04) == 0){
      digitalWrite(OUTPUT_2_PIN, LOW);  
    }else{
      digitalWrite(OUTPUT_2_PIN, HIGH);
    }
    
    // Test ouput pin 3
    if((newOutputState & 0x08) == 0){
      digitalWrite(OUTPUT_3_PIN, LOW);  
    }else{
      digitalWrite(OUTPUT_3_PIN, HIGH);
    }
    
    // Test ouput pin 4
    if((newOutputState & 0x10) == 0){
      digitalWrite(OUTPUT_4_PIN, LOW);  
    }else{
      digitalWrite(OUTPUT_4_PIN, HIGH);
    }
    
    // Test ouput pin 5
    if((newOutputState & 0x20) == 0){
      digitalWrite(OUTPUT_5_PIN, LOW);  
    }else{
      digitalWrite(OUTPUT_5_PIN, HIGH);
    }
    
    // Test ouput pin 6
    if((newOutputState & 0x40) == 0){
      digitalWrite(OUTPUT_6_PIN, LOW);  
    }else{
      digitalWrite(OUTPUT_6_PIN, HIGH);
    }
    
    // Test ouput pin 7
    if((newOutputState & 0x80) == 0){
      digitalWrite(OUTPUT_7_PIN, LOW);  
    }else{
      digitalWrite(OUTPUT_7_PIN, HIGH);
    }

    outputState = newOutputState;
    if(setState){
      setState = false;
    }
  }
  
  if(sendState){
    sendGPIOState();
    sendState = false;
  }
}

/// \brief Send GPIO state on MQTT
void sendGPIOState(){
  for(int i = 0; i < 8; i++){
    memset(topicBuffer, 0, TOPIC_BUFFER_SIZE);
    String tempTopic = topic + "state/" + i + "/";
    tempTopic.toCharArray(topicBuffer, TOPIC_BUFFER_SIZE);
    
    if(((outputState >> i) & 0x01) > 0){ // send 1
      client.publish(topicBuffer, "1");
    }else{                              // send 0
      client.publish(topicBuffer, "0");
    }
  }
}

/// \brief print GPIO state
void printGPIO(uint8_t state){
  Serial.print("GPIO: ");
  for (int i = 0; i < 8; i++) {
    if((state >> 7-i) & 0x01 == 0x01){
      Serial.print("1");
    }else{
      Serial.print("0");
    }
  }
  Serial.print("\n");
}

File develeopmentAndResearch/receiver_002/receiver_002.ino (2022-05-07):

const int INPUT_0_PIN = 2;  // GPIO2  D4
const int INPUT_1_PIN = 0;  // GPIO0  D3
const int INPUT_2_PIN = 4;  // GPIO4  D2
const int INPUT_3_PIN = 5;  // GPIO5  D1
const int INPUT_4_PIN = 14; // GPIO14 D5/SCK
const int INPUT_5_PIN = 12; // GPIO12 D6/MISO
const int INPUT_6_PIN = 13; // GPIO13 D7/MOSI

uint8_t inputState = 0xff;

void setup() {
  Serial.begin(115200);
  
  pinMode(INPUT_0_PIN, INPUT_PULLUP);
  pinMode(INPUT_1_PIN, INPUT_PULLUP);
  pinMode(INPUT_2_PIN, INPUT_PULLUP);
  pinMode(INPUT_3_PIN, INPUT_PULLUP);
  pinMode(INPUT_4_PIN, INPUT_PULLUP);
  pinMode(INPUT_5_PIN, INPUT_PULLUP);
  pinMode(INPUT_6_PIN, INPUT_PULLUP);

  Serial.println("\nStarting...");
}

void loop() {
  uint8_t oldInputState = inputState;
  
  if(digitalRead(INPUT_0_PIN) == LOW){
    inputState |= 0x01;  
  }else{
    inputState &= 0xfe;
  }
  
  if(digitalRead(INPUT_1_PIN) == LOW){
    inputState |= 0x02;  
  }else{
    inputState &= 0xfd;
  }
  
  if(digitalRead(INPUT_2_PIN) == LOW){
    inputState |= 0x04;  
  }else{
    inputState &= 0xfb;
  }
  
  if(digitalRead(INPUT_3_PIN) == LOW){
    inputState |= 0x08;  
  }else{
    inputState &= 0xf7;
  }
  
  if(digitalRead(INPUT_4_PIN) == LOW){
    inputState |= 0x10;  
  }else{
    inputState &= 0xef;
  }
  
  if(digitalRead(INPUT_5_PIN) == LOW){
    inputState |= 0x20;  
  }else{
    inputState &= 0xdf;
  }
  
  if(digitalRead(INPUT_6_PIN) == LOW){
    inputState |= 0x40;  
  }else{
    inputState &= 0xbf;
  }
  
  if(oldInputState != inputState){
    Serial.println(inputState, BIN);
  }

}

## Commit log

2021-03-31 Initial commit and added STL-files for laser transmitters and receptors
    [LaserMazeReceptor_020.skp, LaserMazeReceptor_020_fixed.stl, LaserMazeTransmitterInsert_007.skp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]
2021-12-19 Development stages
2022-05-08 Moved info to final location
    [LaserMazeReceptor_020.skp, LaserMazeReceptor_020_fixed.stl, LaserMazeTransmitterInsert_007.skp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]
2022-05-08 Final Move
    [LaserMazeReceptor_020.skp, LaserMazeReceptor_020_fixed.stl, LaserMazeTransmitterInsert_007.skp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]
2022-05-08 Added KiCad PCB
    [esp8266controllerPCB.kicad_pcb, esp8266controllerPCB.sch]
2022-05-09 Update to version 1.0
    [esp8266controllerPCB.kicad_pcb, esp8266controllerPCB.sch]
2022-05-10 Added Relay PCB
    [esp8266controllerPCBRelay.kicad_pcb, esp8266controllerPCBRelay.sch]
2022-05-22 Added BOM
    [BOM.xlsx]
2022-06-04 Added watchdog to RC controller Corrected code
    [ESP8266GPIORXController.ino, PE1MEW_Led.cpp]
2022-06-18 Added connector
    [BOM.xlsx]
2022-07-31 Added relay software for relay concentrator
2022-12-10 Added images and references to laser and LDR
